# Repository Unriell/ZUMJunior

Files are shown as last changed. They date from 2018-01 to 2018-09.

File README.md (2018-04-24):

# ZUMJunior
BQ ZUM Junior integration on Arduino IDE

Please, visit the [project wiki](https://github.com/bq/ZUMJunior/wiki) for more information.

## Getting Started

### Prerequisites

You need to install latest [Arduino IDE](https://www.arduino.cc/en/Main/Software).

This package has been tested on Arduino IDE 1.8.5.

### Installing

To use the integration with Arduino IDE follow these steps:
1. Open Arduino IDE and go into File -> Preferences.
1. On "Additional Boards Manager URLs:" enter the link to [package_zumjunior_1_8_x_index.json](https://raw.githubusercontent.com/bq/ZUMJunior/master/package_zumjunior_1_8_x_index.json) [right click here and copy link] and press OK.
1. Go to Tools -> Boards -> Board Manager and you will find "ZUM Junior for Arduino 1.8.x" ready to be installed. Install latest version.

Now you can choose your Board **BQ ZUM Junior**.

You can also find some usefull examples for the board available on the IDE.

### Examples

The available examples are explained [here](https://github.com/bq/ZUMJunior/wiki/Examples).

## Flashing Bootloader

The bootloader can be flashed on ZUM Junior using another Arduino board as ISP or any other supported ISP programmer.
For further support check this [link](https://www.arduino.cc/en/Tutorial/ArduinoISP).

## License

This project is licensed under the GPL v3 license.

## Credits

This project relies on [Arduino IDE](https://github.com/arduino/Arduino) to work.

The project is based on [Elektor UNO R4](https://github.com/ElektorLabs/Arduino/)

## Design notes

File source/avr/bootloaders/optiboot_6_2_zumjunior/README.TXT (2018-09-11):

------------------------------------------------------------
bqZUM Junior

This is a slightly modified version to make optiboot compile for 
the ATmega16 too. 

The make rules for the Elektor boards are in Makefile.custom.
The easiest way to make this work is to copy this folder and its 
contents to:

  <Arduino>\hardware\arduino\avr\bootloaders\

where <Arduino> is the path to arduino.exe.

Open a command prompt and navigate to the newly added folder, ex:

  <Arduino>\hardware\arduino\avr\bootloaders\optiboot_6_2_zumjunior\

Enter this folder and then try make commands, like this:

  make atmega328pb LED=D2

This should result in a usable HEX file.
------------------------------------------------------------

This directory contains the Optiboot small bootloader for AVR
microcontrollers, somewhat modified specifically for the Arduino
environment.

Optiboot is more fully described here: http://github.com/Optiboot/optiboot
and is the work of Peter Knight (aka Cathedrow), building on work of Jason P
Kyle, Spiff, and Ladyada.  More recent maintenance and modifications are by
Bill Westfield (aka WestfW)

Arduino-specific issues are tracked as part of the Arduino project
at http://github.com/arduino/Arduino

Most of the information in this file is superceeded by the wiki content at
https://github.com/Optiboot/optiboot/wiki

It's till here "just in case."

------------------------------------------------------------

Building optiboot for Arduino.

Production builds of optiboot for Arduino are done on a Mac in "unix mode"
using CrossPack-AVR-20100115.  CrossPack tracks WINAVR (for windows), which
is just a package of avr-gcc and related utilities, so similar builds should
work on Windows or Linux systems.

One of the Arduino-specific changes is modifications to the makefile to
allow building optiboot using only the tools installed as part of the
Arduino environment, or the Arduino source development tree.  All three
build procedures should yield identical binaries (.hex files) (although
this may change if compiler versions drift apart between CrossPack and
the Arduino IDE.)

Building Optiboot in the Arduino IDE Install.

Work in the .../hardware/arduino/bootloaders/optiboot/ and use the
"omake <targets>" command, which just generates a command that uses
the arduino-included "make" utility with a command like:
    make OS=windows ENV=arduino <targets>
or  make OS=macosx ENV=arduino <targets>
On windows, this assumes you're using the windows command shell.  If
you're using a cygwin or mingw shell, or have one of those in your
path, the build will probably break due to slash vs backslash issues.
On a Mac, if you have the developer tools installed, you can use the
Apple-supplied version of make.
The makefile uses relative paths ("../../../tools/" and such) to find
the programs it needs, so you need to work in the existing optiboot
directory (or something created at the same "level") for it to work.

Building Optiboot in the Arduino Source Development Install.

In this case, there is no special shell script, and you're assumed to
have "make" installed somewhere in your path.
Build the Arduino source ("ant build") to unpack the tools into the
expected directory.
Work in Arduino/hardware/arduino/bootloaders/optiboot and use
    make OS=windows ENV=arduinodev <targets>
or  make OS=macosx ENV=arduinodev <targets>

Programming Chips Using the _isp Targets

The CPU targets have corresponding ISP targets that will actuall
program the bootloader into a chip. "atmega328_isp" for the atmega328,
for example.  These will set the fuses and lock bits as appropriate as
well as uploading the bootloader code.

ISP Targets in Version 5.0 and later:

The isp targets are now built using a separate "Makefile.isp" makefile,
which should make modification easier and more obvious.  This also fixes
the atmega8_isp target problem mentioned below.  The default
configuration assumes an ArduinoISP setup, but you will probably need to
update at least the serial port, since those are different for each
Arduino board and/or system/

ISP Targets in Version 4.6 and earlier:

The older makefiles default to using a USB programmer, but you can use a
serial programmer like ArduinoISP by changing the appropriate variables
when you invoke make:

   make ISPTOOL=stk500v1 ISPPORT=/dev/tty.usbserial-A20e1eAN  \
        ISPSPEED=-b19200 atmega328_isp

The "atmega8_isp" target does not currently work, because the mega8
doesn't have the "extended" fuse that the generic ISP target wants to
pass on to avrdude.  You'll need to run avrdude manually.

Standard Targets

I've reduced the pre-built and source-version-controlled targets
(.hex and .lst files included in the git repository) to just the
three basic 16MHz targets: atmega8, atmega16, atmega328.

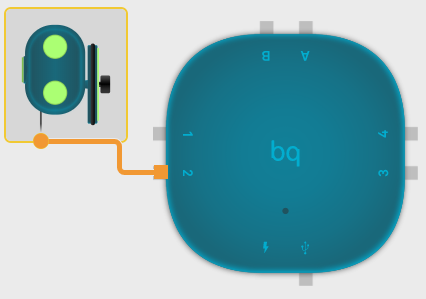
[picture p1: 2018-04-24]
images/examples/RotServo.PNG

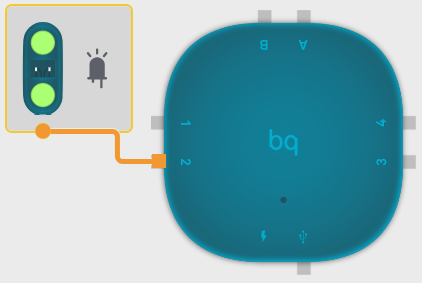
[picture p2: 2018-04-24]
images/examples/LED.PNG

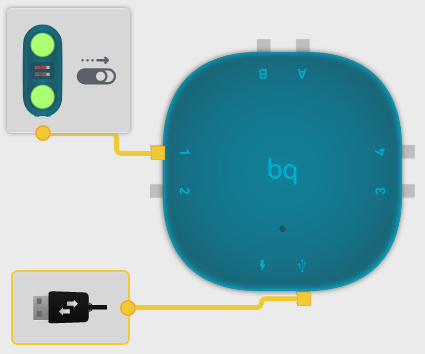
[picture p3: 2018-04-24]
images/examples/Slider.PNG

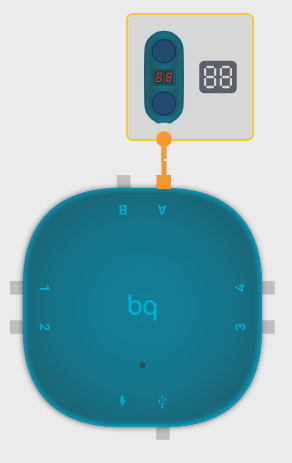
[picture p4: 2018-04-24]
images/examples/7SD.PNG

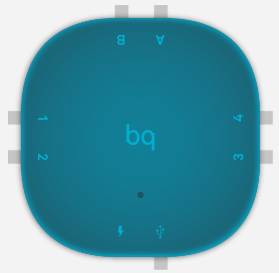
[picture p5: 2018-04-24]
images/examples/ZJ.PNG

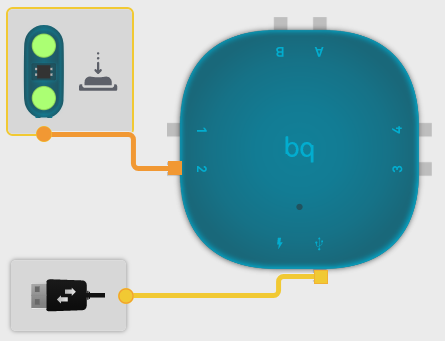
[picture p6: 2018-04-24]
images/examples/PushButton.PNG

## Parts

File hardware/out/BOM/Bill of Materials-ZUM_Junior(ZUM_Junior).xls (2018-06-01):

 |  |  | BILL OF MATERIALS
PROJECT: |  | ZUM_Junior.PrjPcb
TITLE: |  | Bill of Materials For Variant [ZUM_Junior] of Project [ZUM_Junior.PrjPcb] (No PCB Document Selected)
VARIANT: |  | ZUM_Junior
DOCUMENT: |  | Bill of Materials
AUTHOR : |  | Andrés Gullón
DATE : |  | 01/06/2018
REV: |  | <Parameter VersionControl_RevNumber not found>
NOTE | ITEM | Designator | Description | Quantity | Manufacturer | OrderingCode | Supplier | Manufacturer 2 | OrderingCode 2 | Manufacturer 3 | OrderingCode 3 | Manufacturer 4 | OrderingCode 4 | Manufacturer 5 | OrderingCode 5 | Footprint | Value
 | 1 | Buzzer 2 | Buzzer 8.5mm SMD | 1 | Qinlon | YX-8014S-05 |  |  |  |  |  |  |  |  |  | YX-8014S05-2.7 | Buzzer
 | 2 | C1, C2, C8, C11, C12, C14, C19, C20 | C0603_100nF_50V_±10%_X7R | 8 | Kemet | C0603C104K5RAC |  | AVX | 06035C104KAT2A |  |  |  |  |  |  | C0603 | 100nF ±10% 50V
 | 3 | C3, C4, C5, C10, C13, C18 | C0402_2.2uF_16V_±20%_X5R | 6 | TDK | C1005X5R1C225M050BC |  | Taiyo Yuden | EMK105ABJ225MV-F |  |  |  |  |  |  | C0402 | 2,2µF ±20% 16V
 | 4 | C6 |  | 1 | Kemet | C0603C105K3PAC |  |  |  |  |  |  |  |  |  | C0603 | 1uF ±10% 25V
 | 5 | C7, C24 |  | 2 | Murata | GRM31CR61E226KE15L |  |  |  |  |  |  |  |  |  | C1206 | 22uF ±10% 25V
 | 6 | C9, C21 |  | 2 | Kemet | T520B157M006ATE070 |  |  |  |  |  |  |  |  |  | CASE_B_3528-1411 | 150uF ±20% 6V3
 | 7 | C15, C16 | C0402_47pF_16V_±10% | 2 | Kemet | C0402C470K4GAC |  |  |  |  |  |  |  |  |  | C0402 | 47pF ±10% 16V
 | 8 | C17 | C0805_4700pF_250V_±10%_X7R | 1 | TDK | C2012X7R2E472K085AM |  |  |  |  |  |  |  |  |  | C0805 | 4,7nF ±10% 250V
 | 9 | C23 | C0805_1uF_50V_±10%_X7R | 1 | Kemet | C0805C105K5RAC |  |  |  |  |  |  |  |  |  | C0805 | 1uF ±10% 50V
 | 10 | C25 |  | 1 | Kemet | C0402C473K4RAC |  |  |  |  |  |  |  |  |  | C0402 | 47nF ±10% 16V
 | 11 | D1, D2 | Schottky Diode | 2 | NXP | BAT54S |  | Vishay | BAT54S |  |  |  |  |  |  | SOT23-3 | 200mA 30V
 | 12 | D3, D5 | Schottky Diode | 2 | NXP | PMEG3030EP |  |  |  |  |  |  |  |  |  | SOD128 | 3A 30V
 | 13 | D4b | RGB LED Reverse Mount | 1 | WÜrth Elektronik | 156125M173000 |  |  |  |  |  |  |  |  |  | LED1205 Reverse | RGB LED Rev.
 | 14 | F1 | Resettable Fuses | 1 | Bel Fuse | 0ZCG0260BF2B |  | Littelfuse | MINISMDC260F/16-2 | Bourns | MF-MSMF250/16X-2 |  |  |  |  | F1812
 | 15 | F2 | TVS Diode Array | 1 | Würth Elektronik | 82400152 |  | Bourns | CDSOT563-0502 |  |  |  |  |  |  | SOT563
 | 16 | F3 | Resettable Fuses | 1 | Bourns | MF-MSMF050-2 |  |  |  |  |  |  |  |  |  | F1812
 | 17 | J1, J2, J3, J4, J5, J6 | RJ11 4p4c SMD | 6 | Kycon | GMX-SMT2-N-44-TR |  | Cenvalsa | 7641 – T441 |  |  | Molex | 95501-6449 |  |  | RJ11 SMD
 | 18 | L1 | Semi-shielded power inductor | 1 | Bourns | SRN8040-2R2Y |  |  |  |  |  |  |  |  |  | SRN8040 | 2,2µH 6,3A
 | 19 | L2 | L0603_120R_0,025R_3000mA | 1 | Murata | BLM18SG121TN1D |  |  |  |  |  |  |  |  |  | L0603 | 120R 0,025R 3000mA
 | 20 | L3 |  | 1 | Würth Elektronik | 742792012 |  |  |  |  |  |  |  |  |  | L0805 | 33R 0,008R 4000mA
 | 21 | POWER | DC Power Jack 6.4mm 2.0mm | 1 | Würth Elektronik | 694106106102 |  |  |  |  |  |  |  |  |  | 694106106102 | DC Jack
 | 22 | Q1 | N-MOSFET transistor | 1 | Diodes | DMG301NU-13 |  |  |  |  |  |  |  |  |  | SOT23-3
 | 23 | Q2, Q3 | P-MOSFET transistor | 2 | Diodes Incorporated | DMP2035U-7 |  |  |  |  |  |  |  |  |  | SOT23-3
 | 24 | R1, R8 | R0603_1M_0.1W_±5% | 2 | Vishay | CRCW06031M00JN |  |  |  |  |  |  |  |  |  | R0603 | 1M ±5% 0.1W
 | 25 | R2 | R0402_10R_0.063W_±1% | 1 | Vishay | CRCW040210R0FK |  | Yageo | RC0402FR-0710RL |  |  |  |  |  |  | R0402 | '=Resistance+' '+Tolerance+' '+Power
 | 26 | R3, R17 | R0402_1k_0.063W_±5% | 2 | Vishay | CRCW04021K00JN |  |  |  |  |  |  |  |  |  | R0402 | 1k ±5% 0.063W
 | 27 | R4, R11, R19, R20, R21 | R0402_330R_0.063W_±5% | 5 | Vishay | CRCW0402330RJN |  |  |  |  |  |  |  |  |  | R0402 | 330R ±5% 0.063W
 | 28 | R7, R12, R14, R23 | R0402_100k_0.063W_±1%, [NoValue] | 4 | Vishay | CRCW0402100KFK |  |  |  |  |  |  |  |  |  | R0402 | 100k ±1% 0.063W
 | 29 | R10, R16, R22, R25 |  | 4 | Vishay | CRCW040210K0FK |  |  |  |  |  |  |  |  |  | R0402 | 10k ±1% 0.063W
 | 30 | R13 |  | 1 | Vishay | CRCW040252K3FK |  |  |  |  |  |  |  |  |  | R0402 | 52,3k ±1% 0.063W
 | 31 | R15 | R0402_82k_0.063W_±1% | 1 | Vishay | CRCW040282K0FK |  | Yageo | RC0402FR-0782KL |  |  |  |  |  |  | R0402 | 82k ±1% 0.063W
 | 32 | R18 | R0402_75k_0.063W_±1% | 1 | Vishay | CRCW040275K0FK |  | Yageo | RC0402FR-0775KL |  |  |  |  |  |  | R0402 | 75k ±1% 0.063W
 | 33 | R24 | R0402_30k_0.063W_±1% | 1 | Vishay | CRCW040230K0FK |  |  |  |  |  |  |  |  |  | R0402 | 30k ±1% 0.063W
 | 34 | U1 | 8-bit Microcontrollers - MCU 32KB In-system Flash 20MHz 1.8V-5.5V | 1 | Atmel | ATMEGA328PB-AU |  |  |  |  |  |  |  |  |  | TQFP32
 | 35 | U2 | DCDC Step Down Vout= 1-5V; Vin= 12-17V | 1 | MPS | MP1477GTF-Z |  |  |  |  |  |  |  |  |  | SOT-563 - MP1477H
 | 36 | U3 | USB to UART Bridge | 1 | Silicon Labs | CP2104-F03-GMR |  |  |  |  |  |  |  |  |  | QFN24_no_power
 | 37 | U4 | LDO Vin: 3-40V Vout: 1.2-15V @300mA | 1 | Monolithic Power Systems | MP2019GN-Z |  |  |  |  |  |  |  |  |  | SOIC8 EP
 | 38 | USB | Micro USB Type B W/ Rear Pegs | 1 | FCI | 10118194-0001LF |  |  |  |  |  |  |  |  |  | USB_B_W_REAR_PEGS
 | 39 | Y1 | Resonator 16MHz | 1 | Murata | CSTCE16M0V53-R0 |  |  |  |  |  |  |  |  |  | Resonator_1.3x3.2 | 16MHz
NOTES:

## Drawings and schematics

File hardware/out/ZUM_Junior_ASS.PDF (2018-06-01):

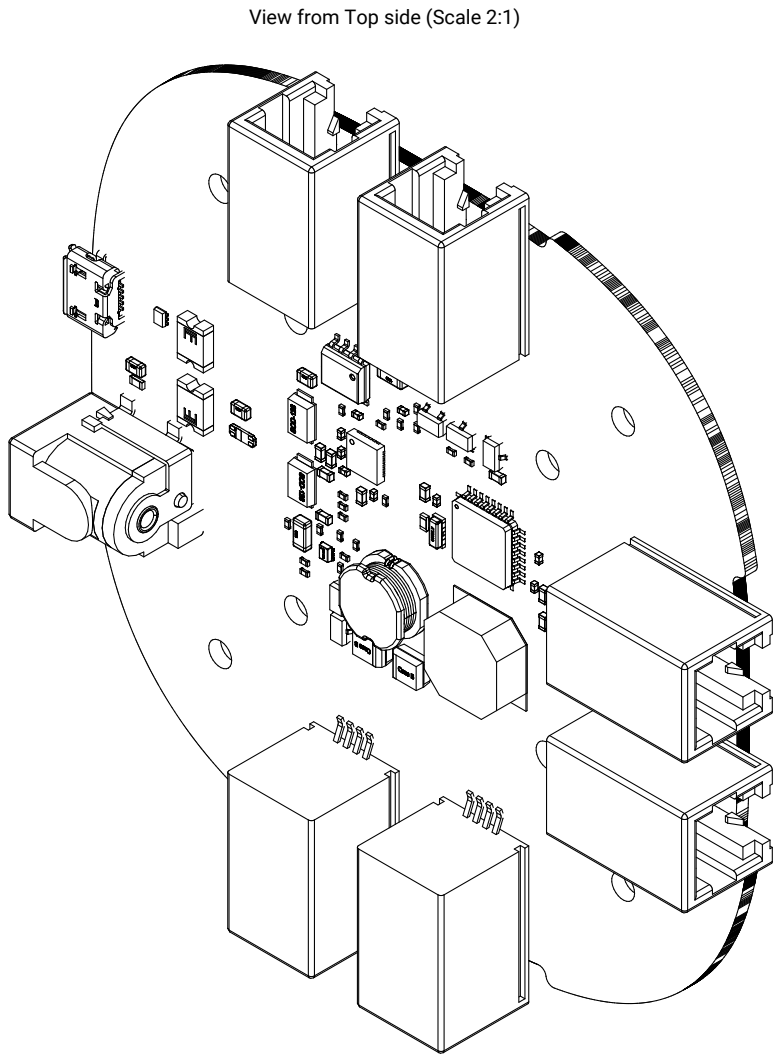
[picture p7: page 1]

View from Top side (Scale 2:1)

ZUM_Junior | SCALE | 2:1

REVISION | =1.G.3
UNIT | UNLESS OTHERWISE SPECIFIED: DIMENSIONS ARE IN MILLIMETERS

PROJECTION

A3 | SHEET 1 OF 2

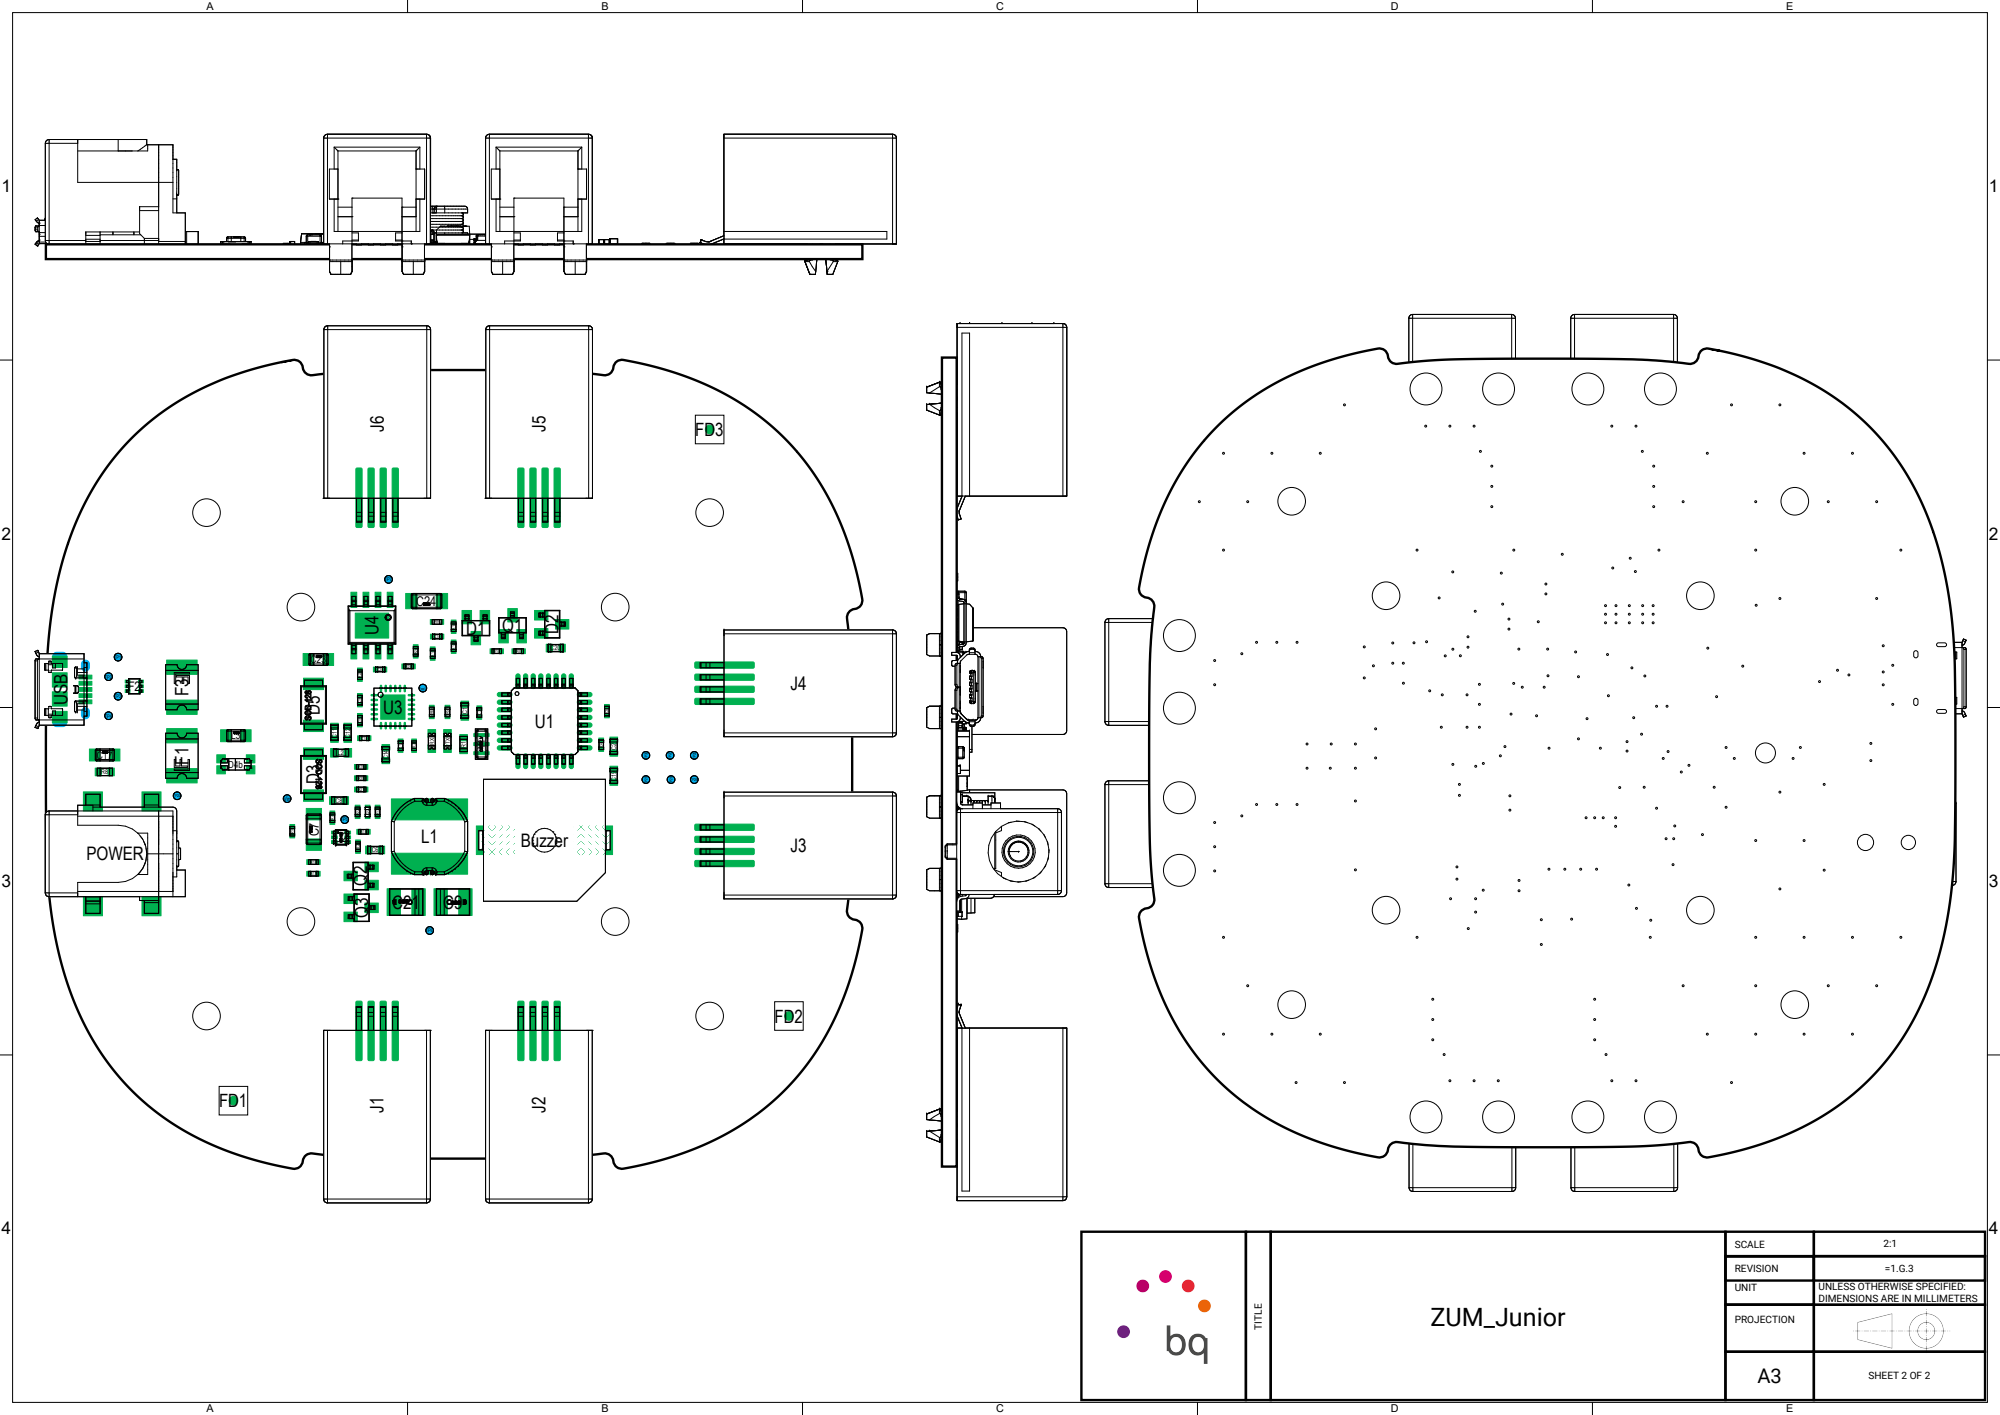
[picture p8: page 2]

ZUM_Junior | SCALE | 2:1

REVISION | =1.G.3
UNIT | UNLESS OTHERWISE SPECIFIED: DIMENSIONS ARE IN MILLIMETERS

PROJECTION

A3 | SHEET 2 OF 2

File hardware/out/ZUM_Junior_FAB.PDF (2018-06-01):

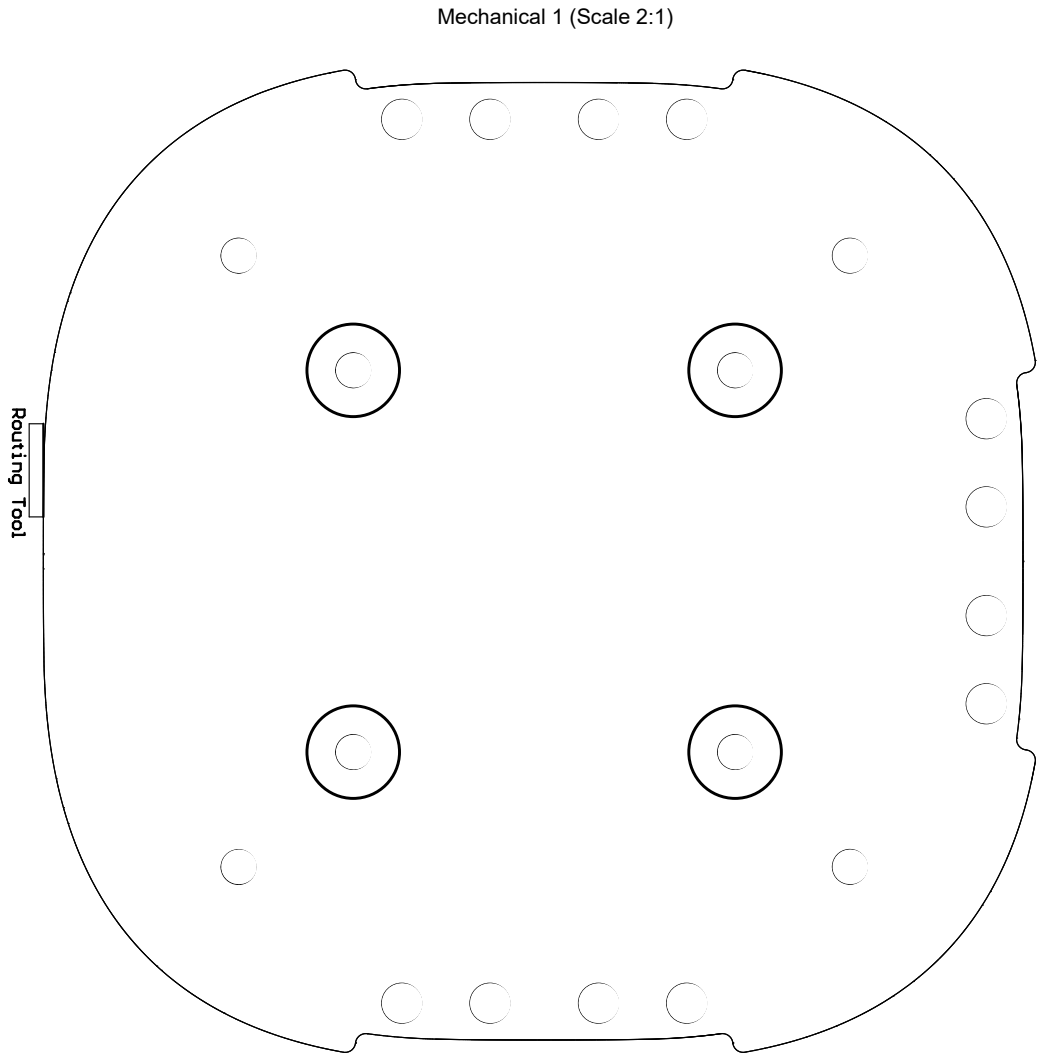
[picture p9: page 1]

SURFACE FINISH: | | SOLDERMASK COLOR: TITLE ZUM_Junior | SCALE | 2:1

Immersion Tin | Blue | SILKSCREEN COLOR: White

REVISION | =1.G.3
UNIT | UNLESS OTHERWISE SPECIFIED: DIMENSIONS ARE IN MILLIMETERS

PROJECTION

A3 | SHEET 1 OF 3

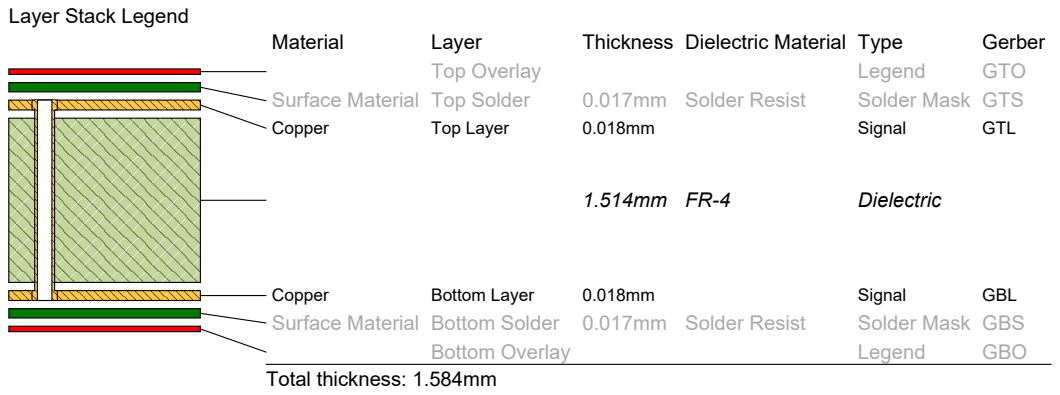
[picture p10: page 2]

SURFACE FINISH: | | SOLDERMASK COLOR: TITLE | SCALE | 2:1

Immersion Tin | Blue | SILKSCREEN COLOR: White

REVISION | =1.G.3
UNIT | UNLESS OTHERWISE SPECIFIED:

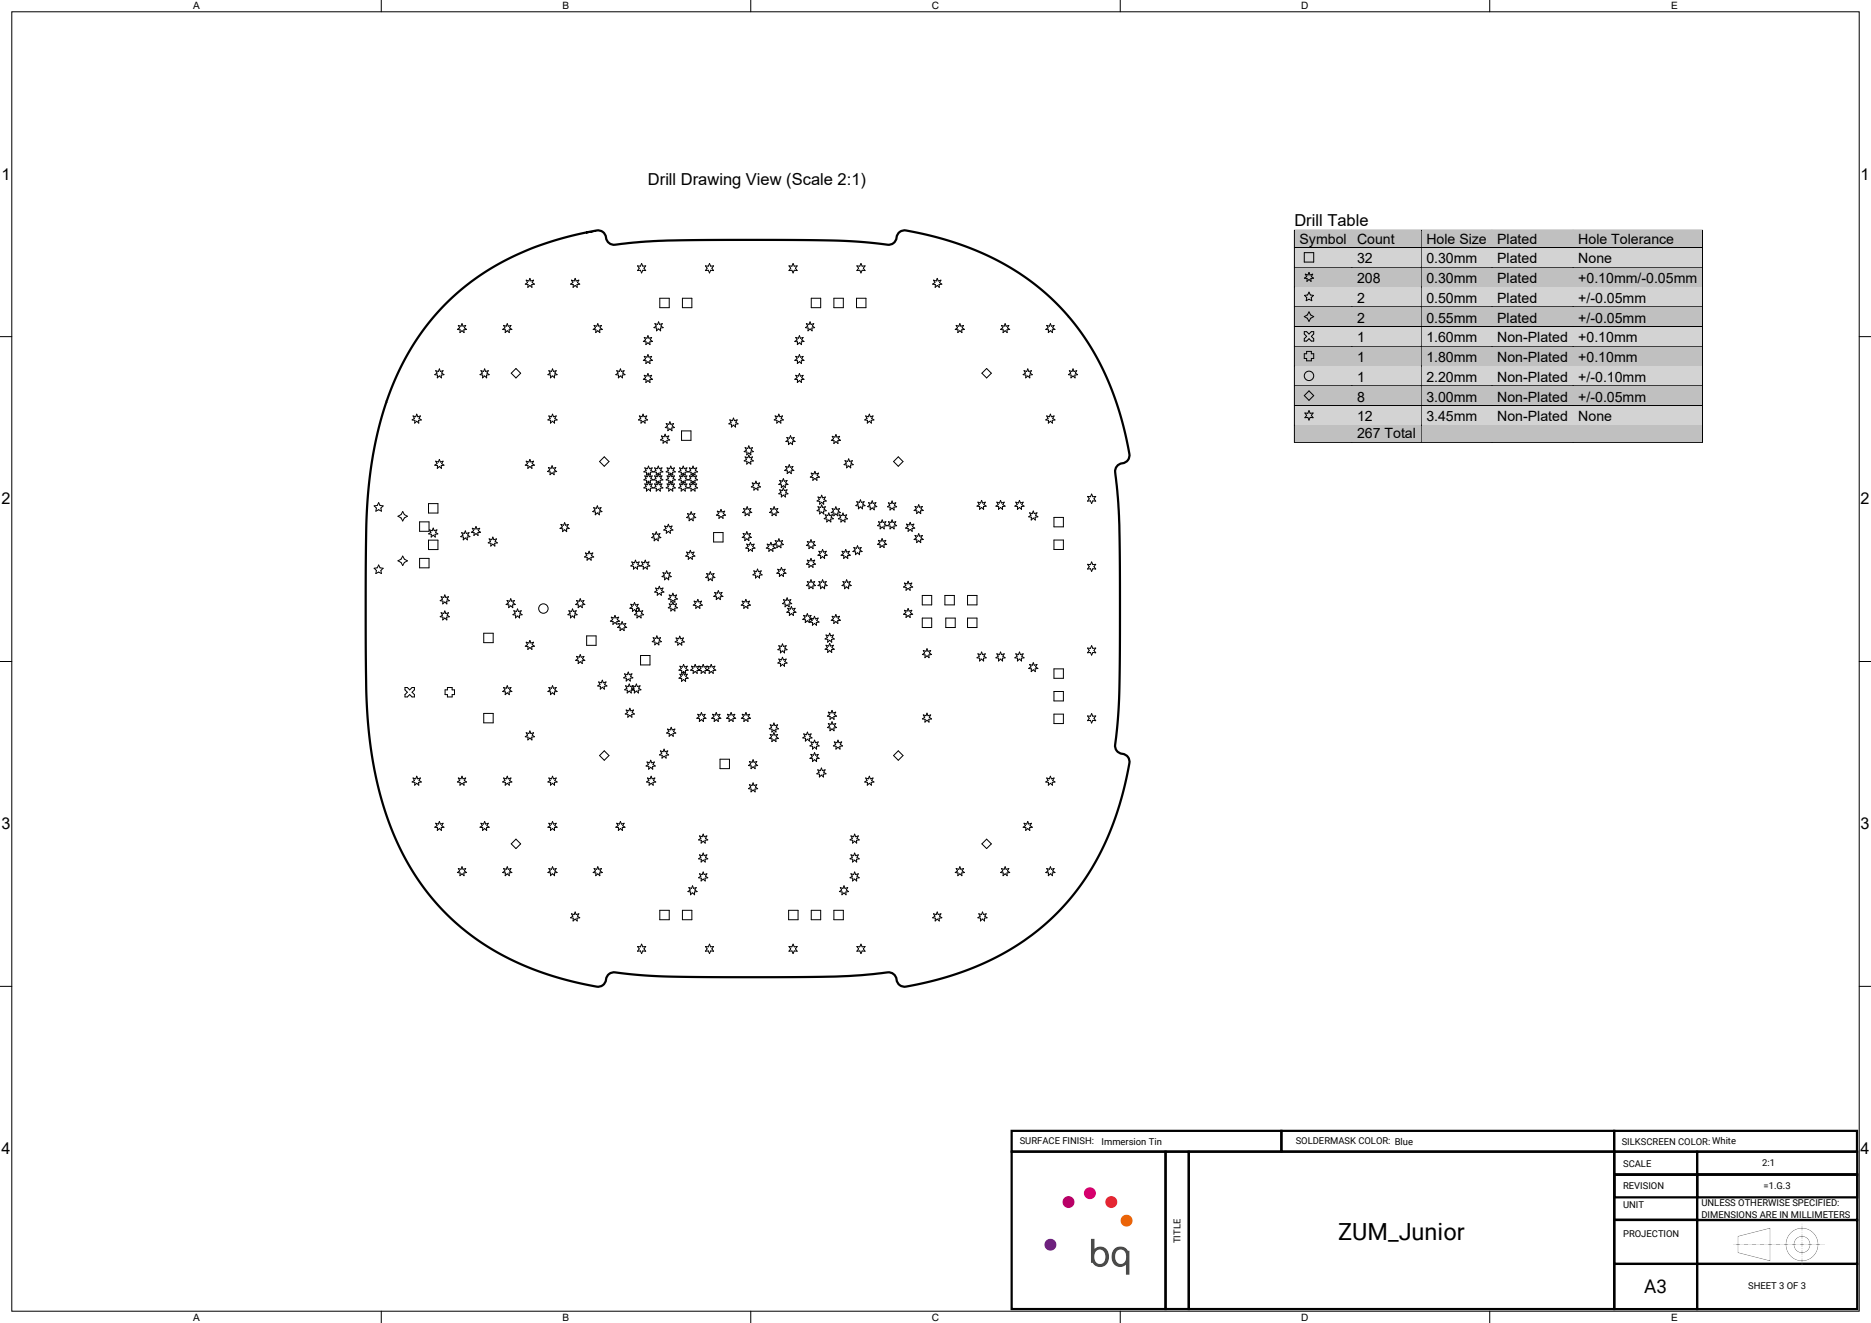
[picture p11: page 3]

Drill Drawing View (Scale 2:1)

Symbol | Count | Hole Size | Plated | Hole Tolerance

32 | 0.30mm | Plated | None
208 | 0.30mm | Plated | +0.10mm/-0.05mm
2 | 0.50mm | Plated | +/-0.05mm
2 | 0.55mm | Plated | +/-0.05mm
1 | 1.60mm | Non-Plated | +0.10mm
1 | 1.80mm | Non-Plated | +0.10mm
1 | 2.20mm | Non-Plated | +/-0.10mm
8 | 3.00mm | Non-Plated | +/-0.05mm
12 | 3.45mm | Non-Plated | None
267 Total

SURFACE FINISH: | | SOLDERMASK COLOR: TITLE | SCALE | 2:1

Immersion Tin | Blue | SILKSCREEN COLOR: White

REVISION | =1.G.3
UNIT | UNLESS OTHERWISE SPECIFIED:

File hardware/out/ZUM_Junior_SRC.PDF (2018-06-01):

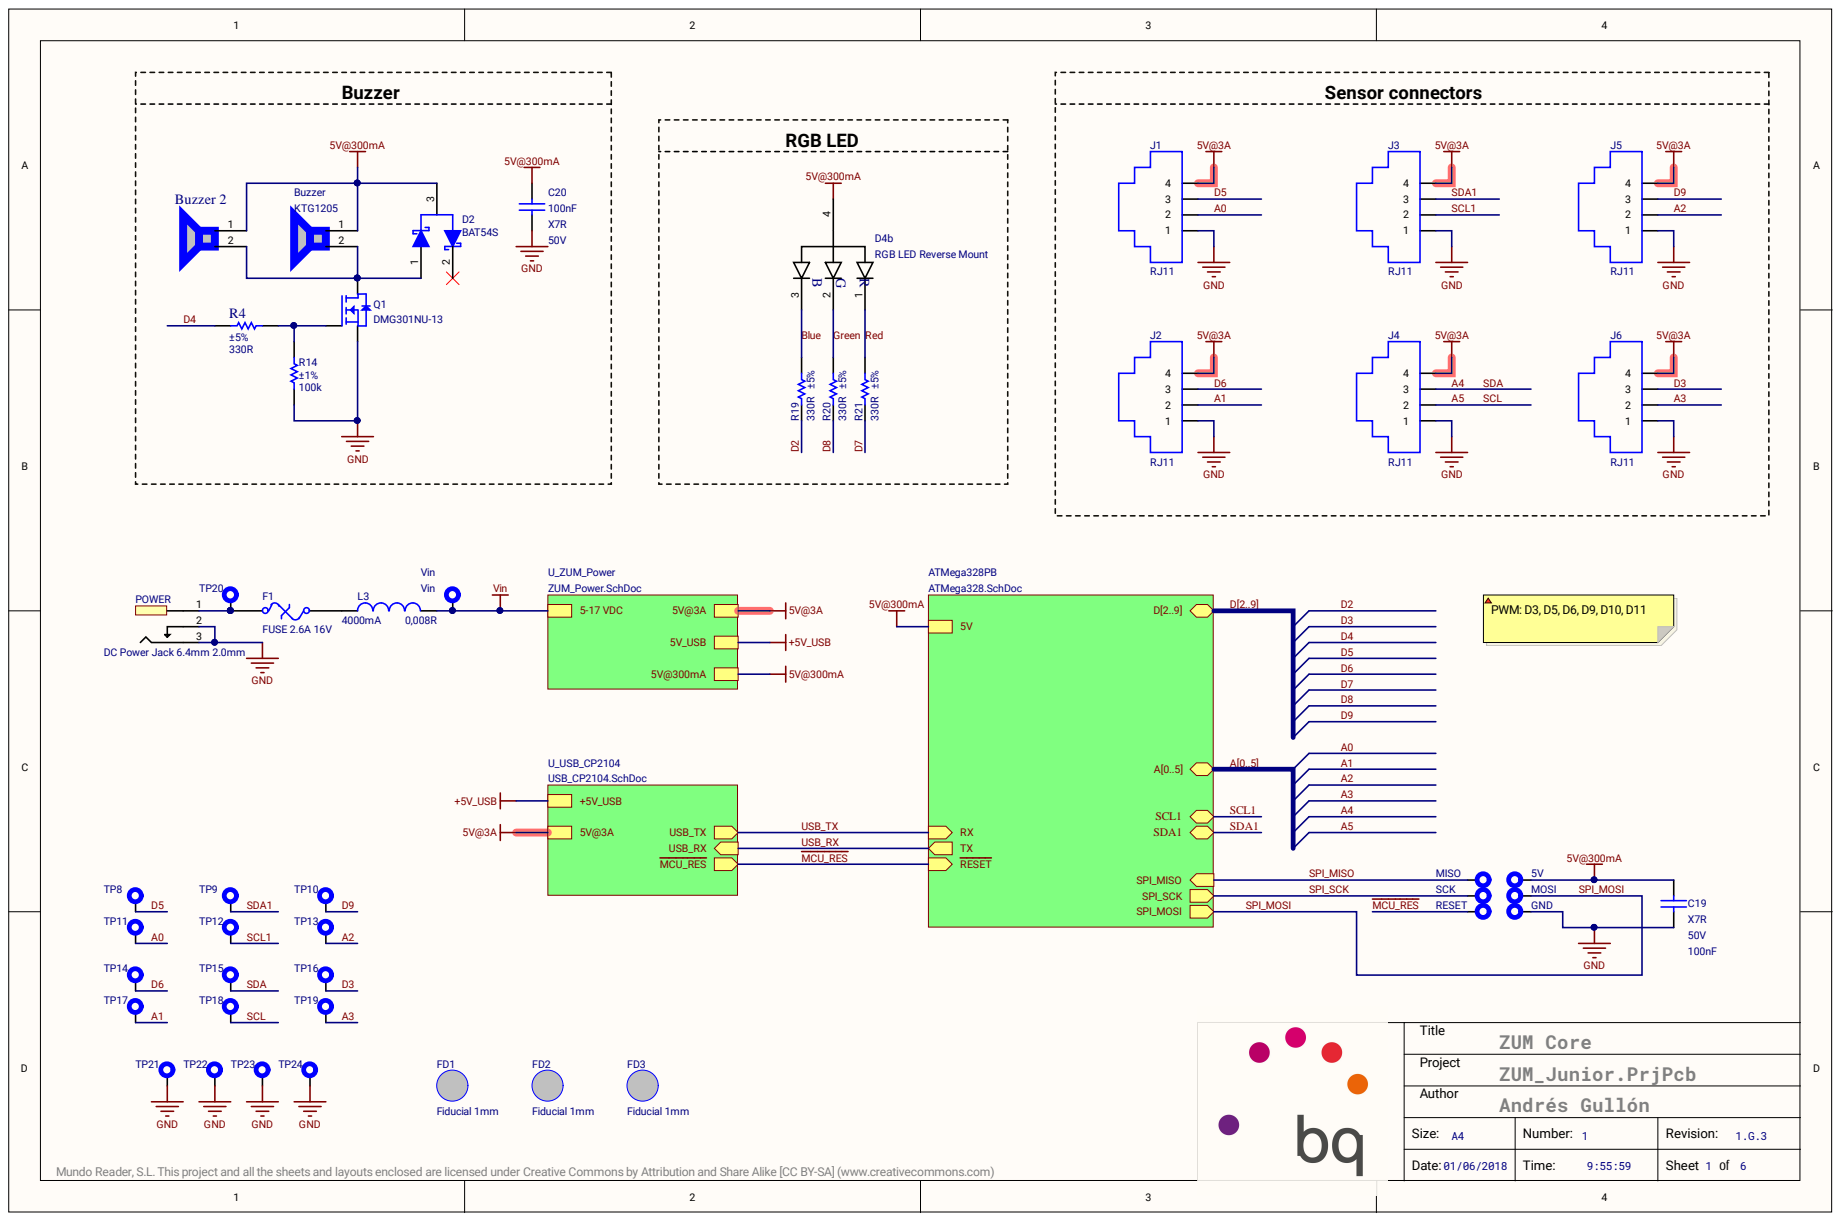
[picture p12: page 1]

Siz e : A 4 | Numbe r : | R evision: 1 . G . 3

D ate / | Time : : | She e t of

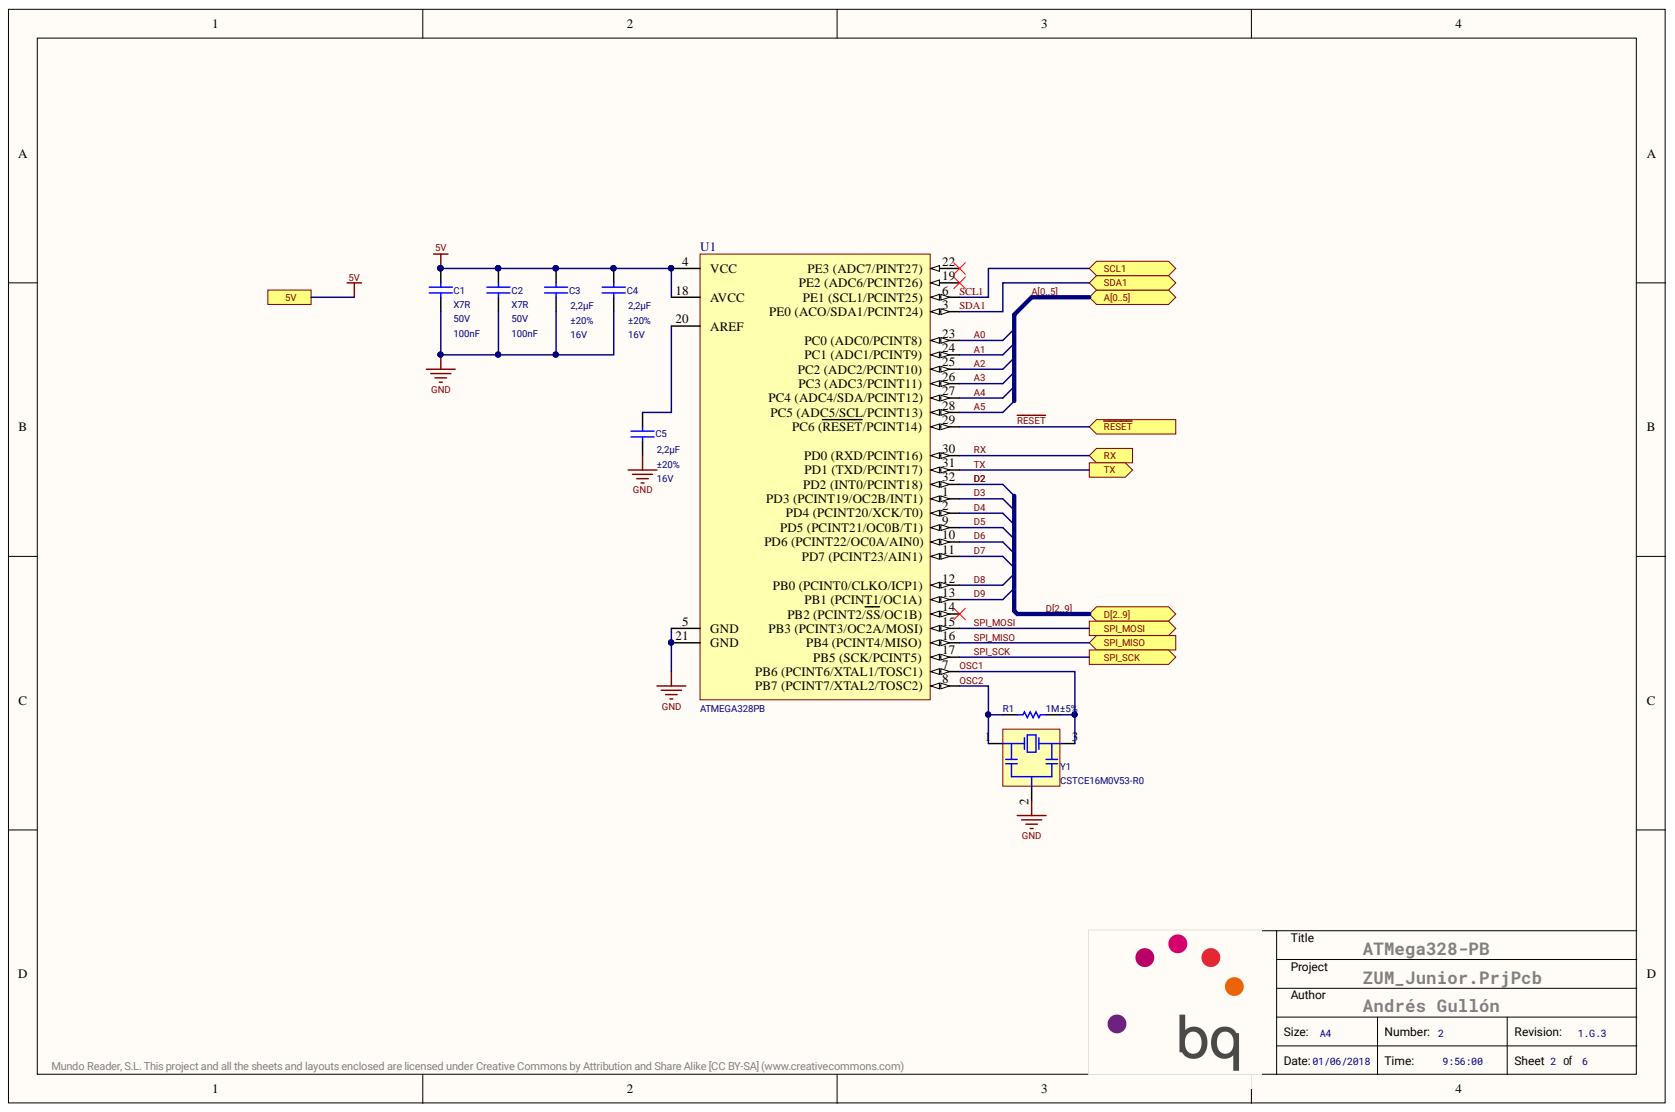
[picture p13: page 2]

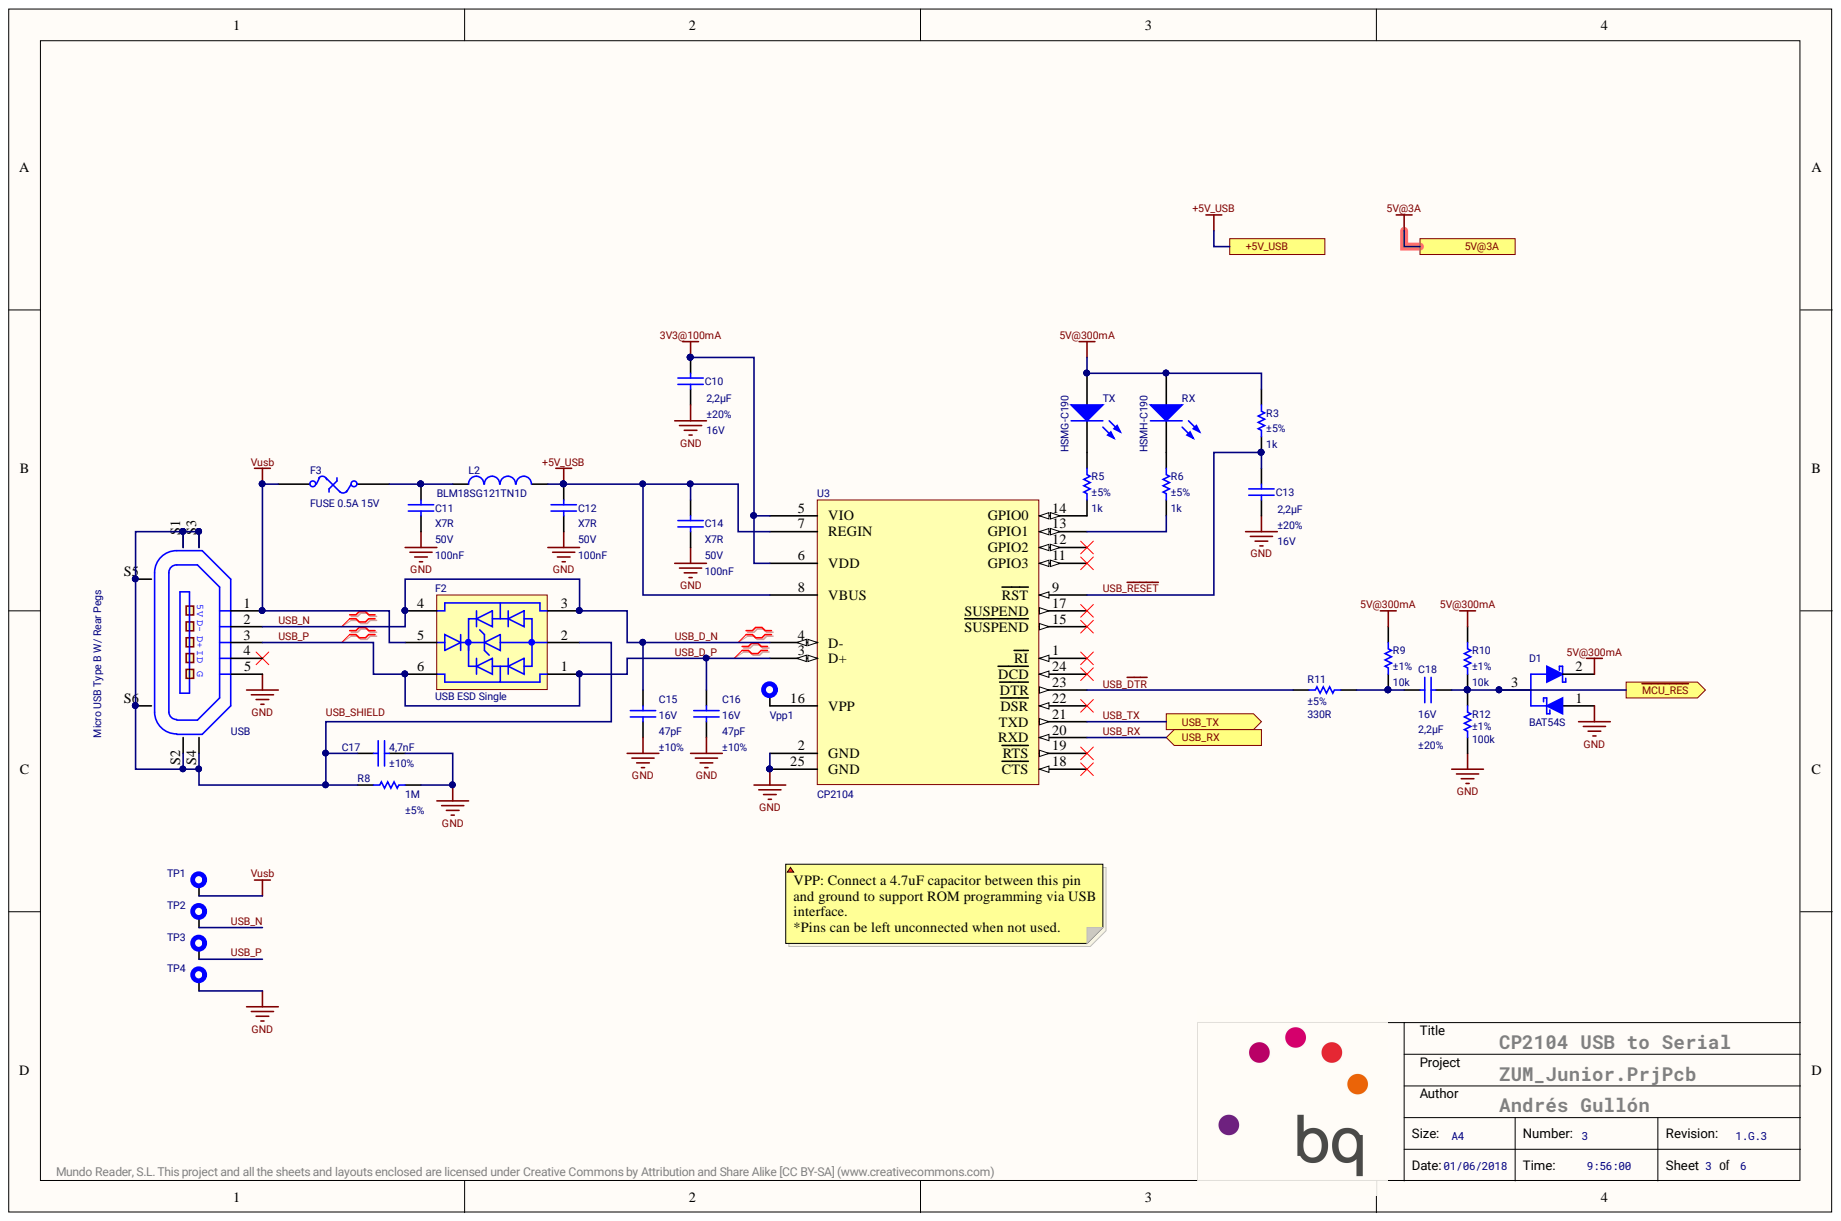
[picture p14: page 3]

USB icro USB Type B W/ Rear Pegs

and ground to support ROM programming via USB
interface.
*Pins can be left unconnected when not used.

Size: A4 | Number: 3 | Revision: 1.G.3

Date: 01/06/2018 | Time: 9:56:00 | Sheet 3 of 6

Mundo Reader, S.L. This project and all the sheets and layouts enclosed are licensed under Creative Commons by Attribution and Share Alike [CC BY-SA](www.creativecommons.com)

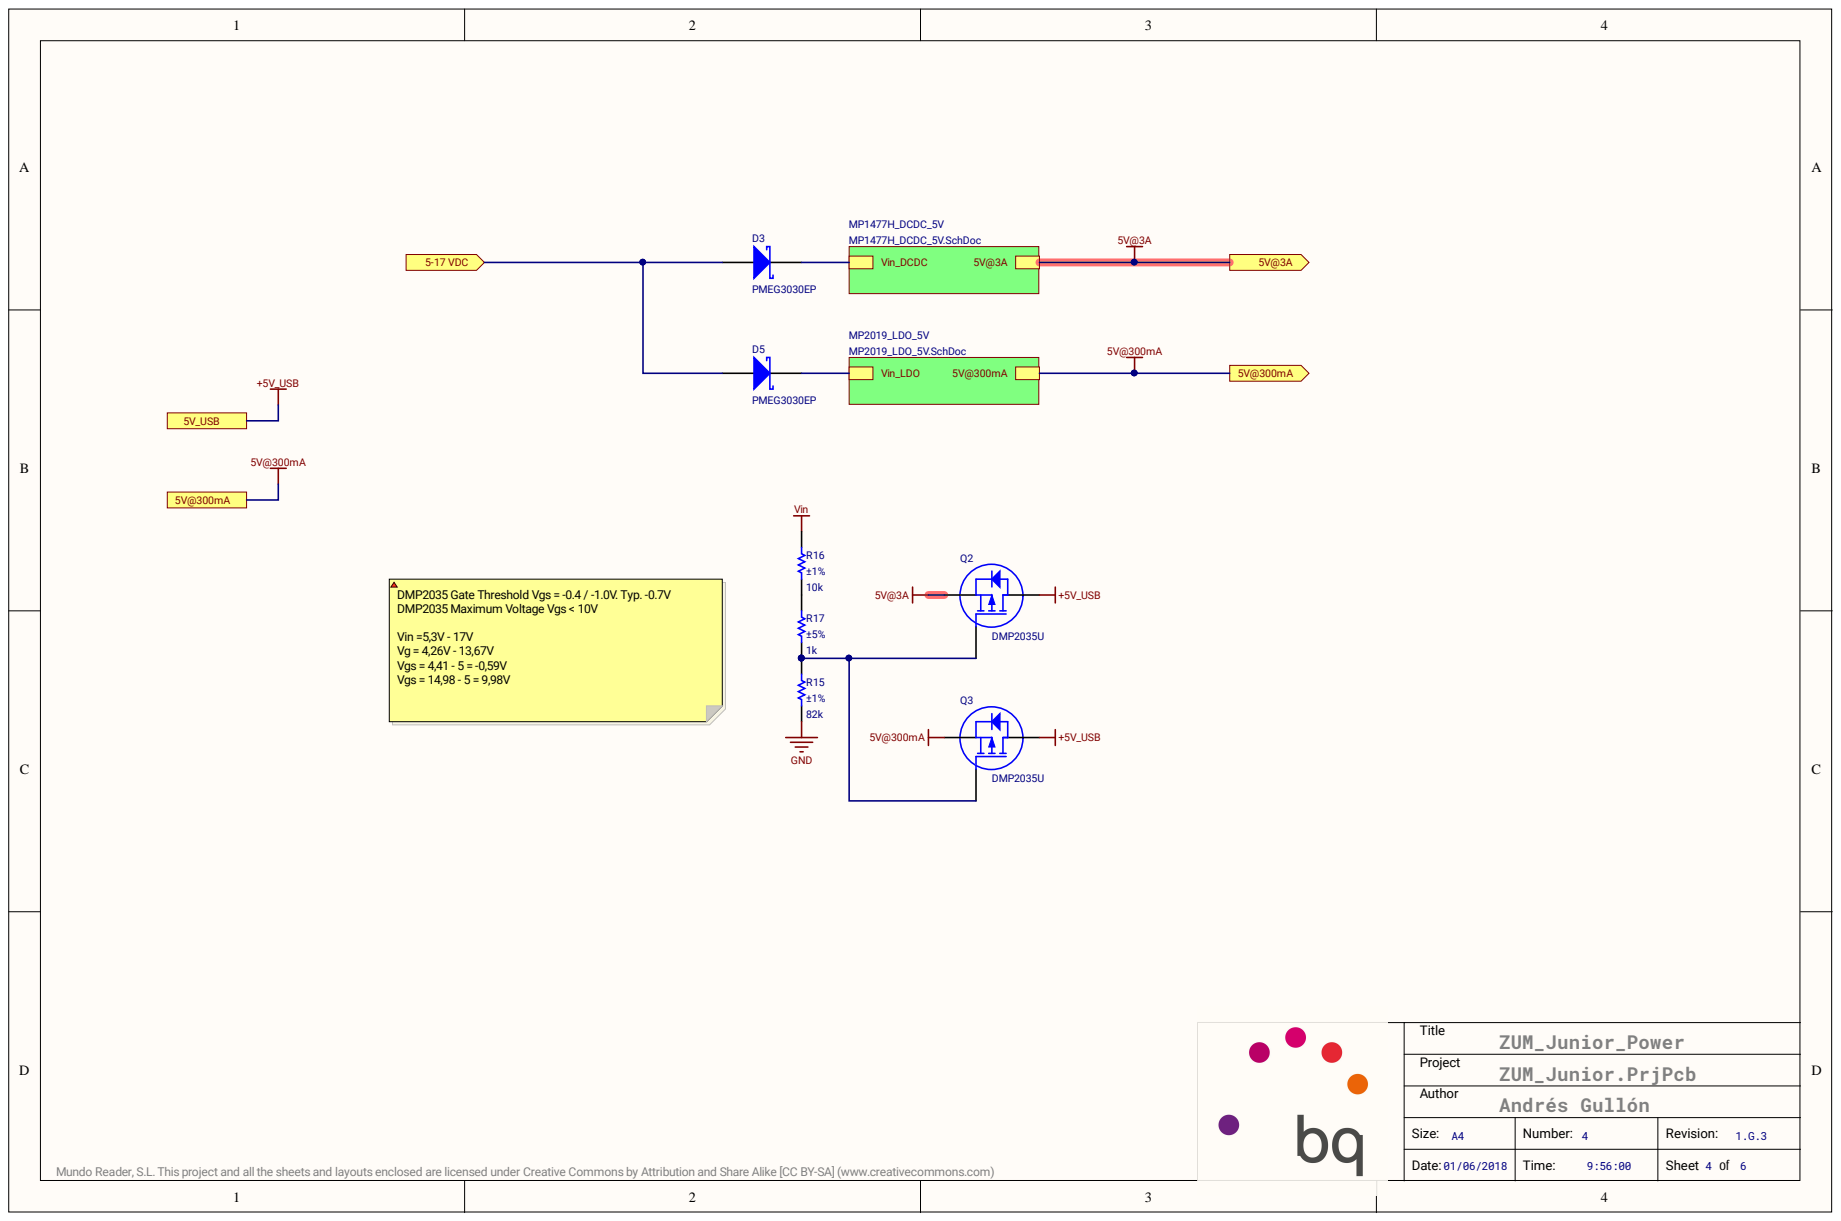
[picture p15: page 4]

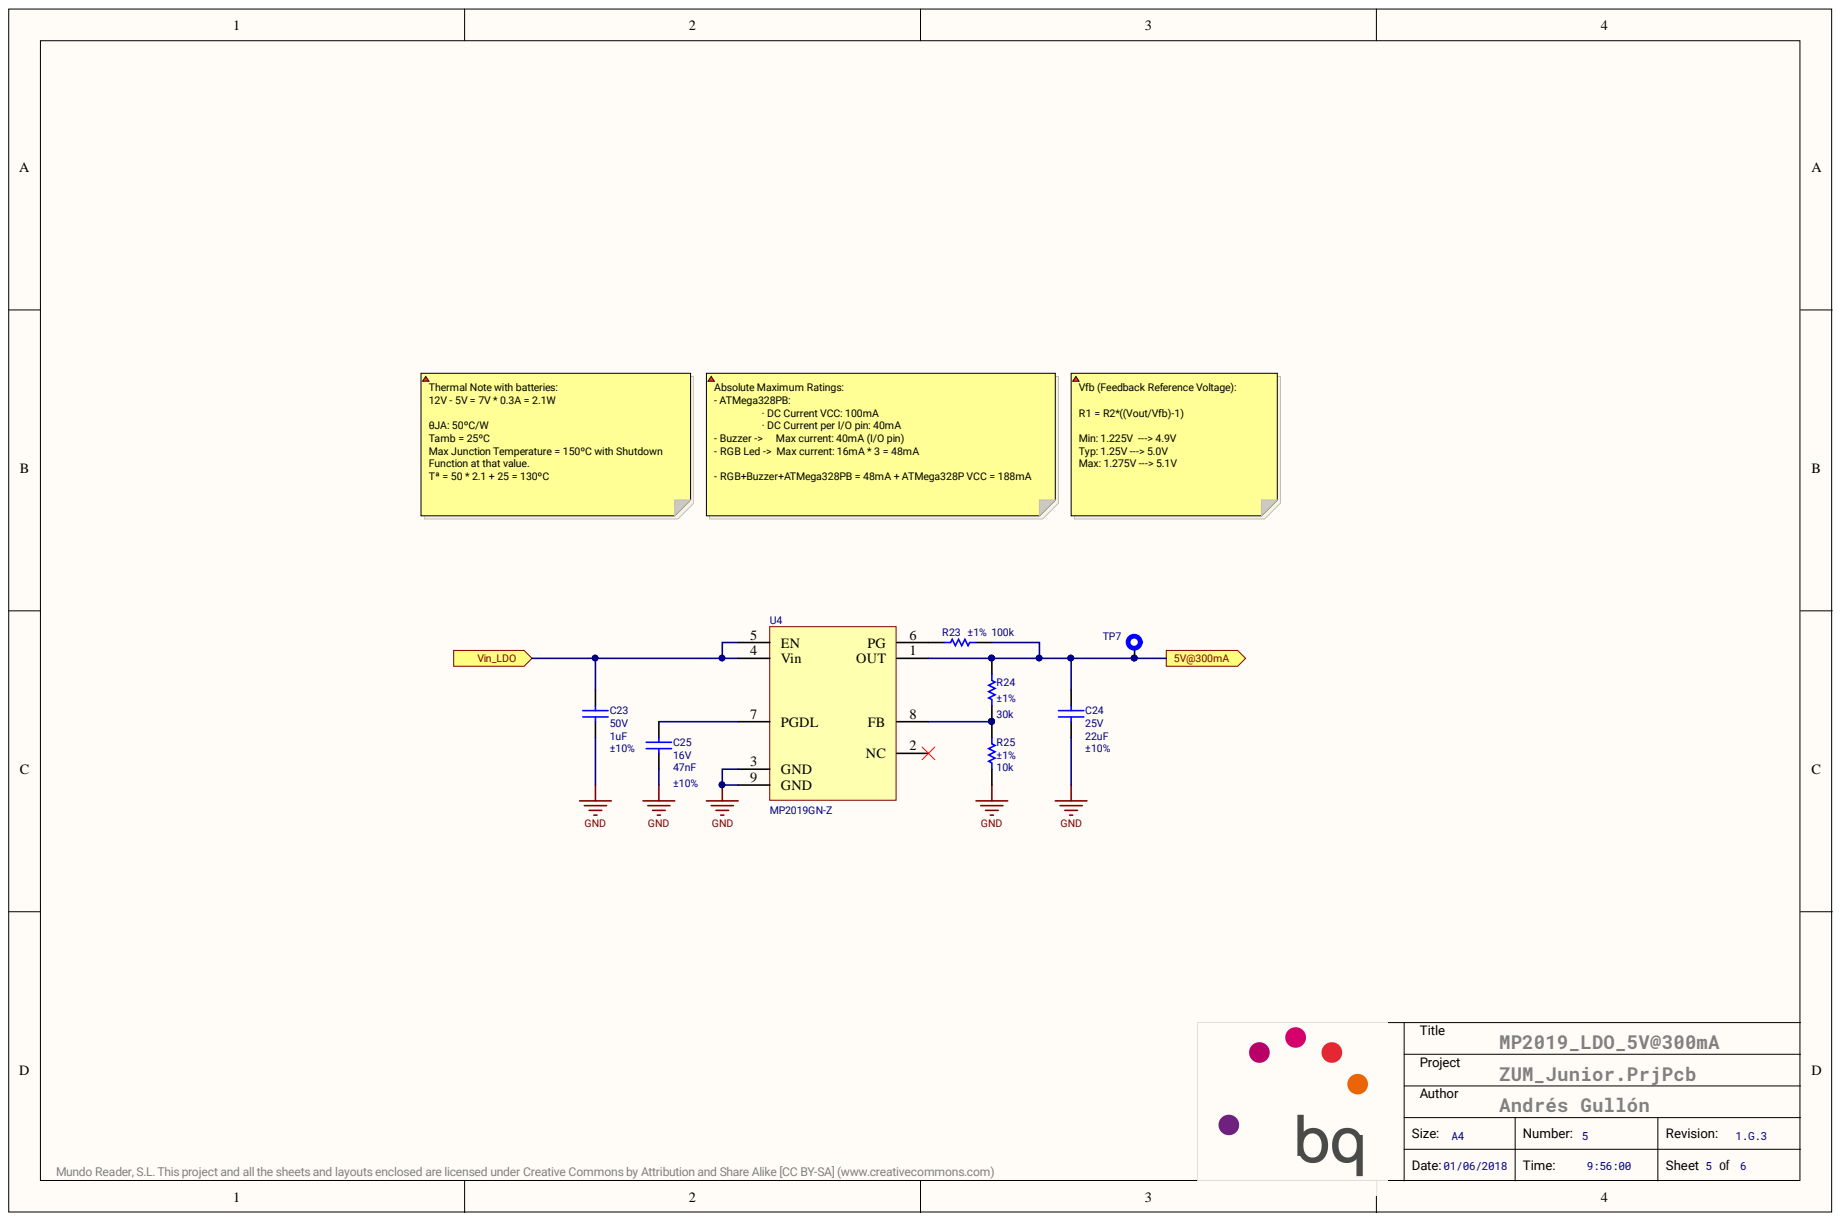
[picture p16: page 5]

on at that value

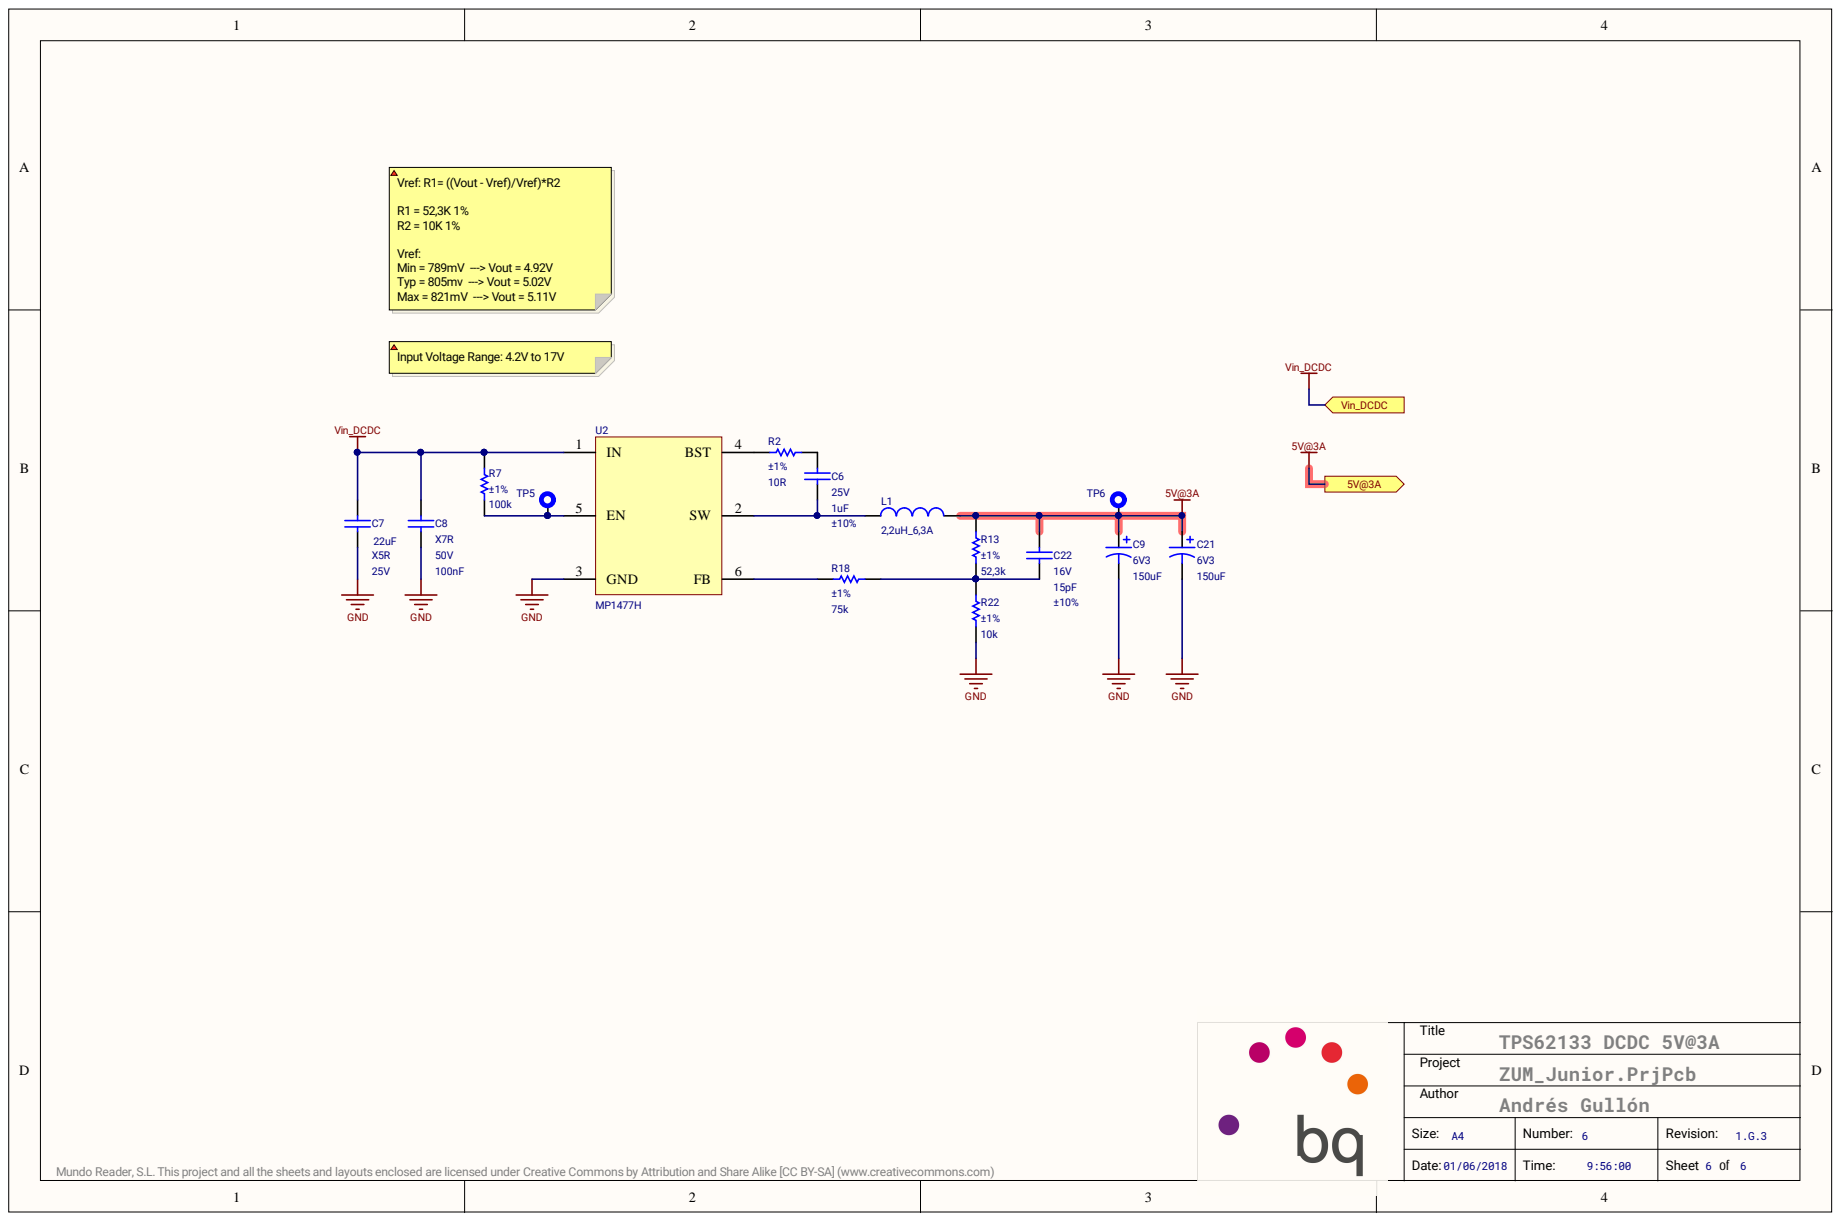
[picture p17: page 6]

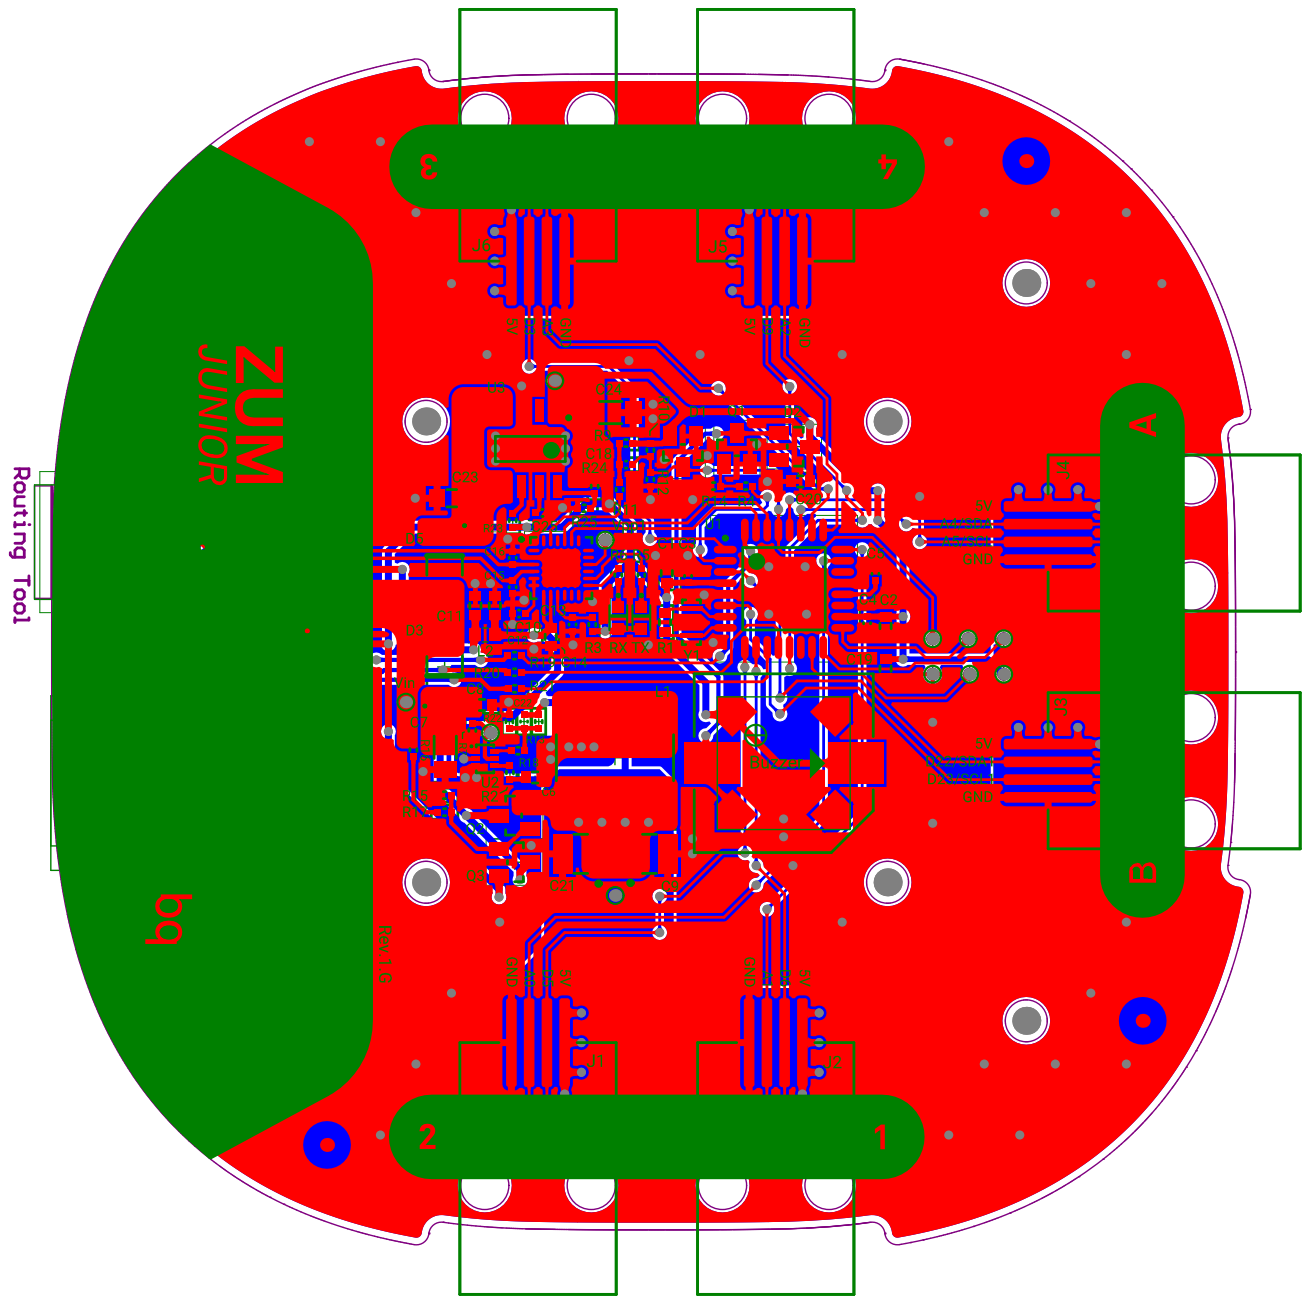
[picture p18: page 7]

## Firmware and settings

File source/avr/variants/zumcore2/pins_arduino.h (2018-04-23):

/*
  pins_arduino.h - Pin definition functions for Arduino
  Part of Arduino - http://www.arduino.cc/

  Copyright (c) 2007 David A. Mellis

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
  $Id: wiring.h 249 2007-02-03 16:52:51Z mellis $
*/

#ifndef Pins_Arduino_h
#define Pins_Arduino_h

#include <avr/pgmspace.h>

#include "avr/iom328p.h"

#undef LED_BUILTIN
#define LED_BUILTIN  (8)

// Pin  0 -  7: PD0-7
// Pin  8 - 13: PB0-5
// Pin 14 - 19: PC0-5
// Pin 20 - 21: PE2-3
// Pin 22 - 23: PE0-1

#define NUM_DIGITAL_PINS  (24) // ZUM Junior and ZUM Core 2 have 24 instead of 20 GPIOs.
#define NUM_ANALOG_INPUTS   (8) // ZUM Junior and ZUM Core 2 have 8 instead of 6 analog inputs.

#define analogInputToDigitalPin(p)  (((p)<8)? (p)+14 : -1)

#define digitalPinHasPWM(p)  ((p)<=3) || (p)==5 || (p)==6 || (p)==9 || (p)==10 || (p)==11)

// SPI, SPI is also SPI0
static const uint8_t SS   = 10; // PB2
static const uint8_t MOSI = 11; // PB3
static const uint8_t MISO = 12; // PB4
static const uint8_t SCK  = 13; // PB5
// SPI0
static const uint8_t SS0   = 10; // PB2
static const uint8_t MOSI0 = 11; // PB3
static const uint8_t MISO0 = 12; // PB4
static const uint8_t SCK0  = 13; // PB5
// SPI1
static const uint8_t SS1   = 20; // PE2
static const uint8_t MOSI1 = 21; // PE3
static const uint8_t MISO1 = 14; // PC0
static const uint8_t SCK1  = 15; // PC1

// I2C / TWI, SDA/SCL is also SDA0/SCL0
static const uint8_t SDA = 18; // PC4
static const uint8_t SCL = 19; // PC5
// I2C0
static const uint8_t SDA0 = 18; // PC4
static const uint8_t SCL0 = 19; // PC5
// I2C1
static const uint8_t SDA1 = 22; // PE0
static const uint8_t SCL1 = 23; // PE1

// Analog inputs
static const uint8_t A0 = 14; // PC0
static const uint8_t A1 = 15; // PC1
static const uint8_t A2 = 16; // PC2
static const uint8_t A3 = 17; // PC3
static const uint8_t A4 = 18; // PC4
static const uint8_t A5 = 19; // PC5
static const uint8_t A6 = 20; // PE2
static const uint8_t A7 = 21; // PE3

// Pin Change Interrupt
#define digitalPinToPCICR(p)    (((p)<=23) ? (&PCICR) : ((uint8_t *)0))
                                // Port D         Port B          Port C     Port C
#define digitalPinToPCICRbit(p) (((p)<=7)? 2 : (((p)<=13)? 0 : (((p)<=19)? 1 : 3)))
#define digitalPinToPCMSK(p)    (((p)<=7)? (&PCMSK2) : (((p)<=13)? (&PCMSK0) : (((p)<=19)? (&PCMSK1) : (((p)<=23)? (&PCMSK3) : ((uint8_t *)0)))))
#define digitalPinToPCMSKbit(p) (((p)<=7)? (p) : (((p)<=13)? ((p)-8) : (((p)<=19)? ((p)-14) : ((p)<=21)? ((p)-17) : ((p)-22))))

#define digitalPinToInterrupt(p)  ((p) == 2 ? 0 : ((p) == 3 ? 1 : NOT_AN_INTERRUPT))

#ifdef ARDUINO_MAIN


// these arrays map port names (e.g. port B) to the
// appropriate addresses for various functions (e.g. reading
// and writing)
const uint16_t PROGMEM port_to_mode_PGM[] = {
	NOT_A_PORT,
	NOT_A_PORT,
	(uint16_t) &DDRB,
	(uint16_t) &DDRC,
	(uint16_t) &DDRD,
	(uint16_t) &DDRE,
};

const uint16_t PROGMEM port_to_output_PGM[] = {
	NOT_A_PORT,
	NOT_A_PORT,
	(uint16_t) &PORTB,
	(uint16_t) &PORTC,
	(uint16_t) &PORTD,
	(uint16_t) &PORTE,
};

const uint16_t PROGMEM port_to_input_PGM[] = {
	NOT_A_PORT,
	NOT_A_PORT,
	(uint16_t) &PINB,
	(uint16_t) &PINC,
	(uint16_t) &PIND,
	(uint16_t) &PINE,
};

const uint8_t PROGMEM digital_pin_to_port_PGM[] = {
	PD, /* 0 */
	PD,
	PD,
	PD,
	PD,
	PD,
	PD,
	PD,
	PB, /* 8 */
	PB,
	PB,
	PB,
	PB,
	PB,
	PC, /* 14 */
	PC,
	PC,
	PC,
	PC,
	PC,
	PE, /* 20 */
	PE,
	PE,
	PE,
};

const uint8_t PROGMEM digital_pin_to_bit_mask_PGM[] = {
	_BV(0), /* 0, port D */
	_BV(1),
	_BV(2),
	_BV(3),
	_BV(4),
	_BV(5),
	_BV(6),
	_BV(7),
	_BV(0), /* 8, port B */
	_BV(1),
	_BV(2),
	_BV(3),
	_BV(4),
	_BV(5),
	_BV(0), /* 14, port C */
	_BV(1),
	_BV(2),
	_BV(3),
	_BV(4),
	_BV(5),
	_BV(2), /* 20, port E, PE2 is AD6 */
	_BV(3), // PE3 is AD7
	_BV(0), // PE0
	_BV(1), // PE1
};

const uint8_t PROGMEM digital_pin_to_timer_PGM[] = {
	TIMER3A, /* 0 - port D */
	TIMER4A,
	TIMER3B,
	TIMER2B,
	NOT_ON_TIMER,
	TIMER0B,
	TIMER0A,
	NOT_ON_TIMER,
	NOT_ON_TIMER, /* 8 - port B */
	TIMER1A,
	TIMER1B,
	TIMER2A,
	NOT_ON_TIMER,
	NOT_ON_TIMER,
	NOT_ON_TIMER, /* 14 - port C */
	NOT_ON_TIMER,
	NOT_ON_TIMER,
	NOT_ON_TIMER,
	NOT_ON_TIMER,
	NOT_ON_TIMER,
	NOT_ON_TIMER, /* 20 - port E */
	NOT_ON_TIMER,
	NOT_ON_TIMER,
	NOT_ON_TIMER,
};

#endif
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

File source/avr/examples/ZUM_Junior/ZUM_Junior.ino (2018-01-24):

/*************************************************************/
/**                 BQ ZUM JUNIOR - Example                 **/
/**                                                         **/
/** Connections:                                            **/
/**   - Port 1 (D9/A2): LED Yellow                          **/
/**   - Port 2 (D3/A3):                                     **/
/**   - Port 3 (D5/A0): LED Green                           **/
/**   - Port 4 (D6/A1): LED Red                             **/
/**   - Port A (D20/D21/I2C1): 7 Segment Display            **/
/**   - Port B (A4/A5/I2C0): Sensor Multiple                **/
/*************************************************************/
/**  Temperature Displayed in 7 Segment Display             **/
/**  Distance represented in RGB LED                        **/
/**  In low light condition White LEDs are turned ON        **/
/**  Color sensor is represented in RGB LED                 **/
/*************************************************************/
/**  Needed external library: SoftPWM                       **/
/*************************************************************/

#include <BQZUM_DistSensor.h>
#include <BQZUM_TempSensor.h>
#include <BQZUM_ColorSensor.h>
#include <BQZUM_SegmentDisplay.h>
#include <SoftPWM.h>

#define   LED_RGB_RED   7
#define   LED_RGB_GREEN 8
#define   LED_RGB_BLUE  2
#define   BUZZER        4

#define   BLOQ_LED_G_GREEN  A0
#define   BLOQ_LED_G_WHITE  5
#define   BLOQ_LED_Y_YELLOW A2
#define   BLOQ_LED_Y_WHITE  9
#define   BLOQ_LED_R_RED    A1
#define   BLOQ_LED_R_WHITE  6

#define   NOTE_E6       1319
#define   NOTE_B4       494
#define   QUARTER_NOTE  250
#define   EIGHT_NOTE    125

// Declare all sensors
BQZUM_DistSensor      ALPSSensor;
BQZUM_ColorSensor     ColorSensor;
BQZUM_TempSensor      TempSensor;
BQZUM_SegmentDisplay  SegmentDisplay;

void setup() {
  ALPSStat    ALPS_Status = ALPS_OK;
  TempStat    Temp_Status = TEMP_OK;
  ColorStat   Color_Status = COLOR_OK;
  SegmentStat Segment_Status = SEGMENT_OK;
  
  pinMode (LED_RGB_RED,   OUTPUT);
  pinMode (LED_RGB_GREEN, OUTPUT);
  pinMode (LED_RGB_BLUE,  OUTPUT);
  pinMode (BUZZER,        OUTPUT);
  pinMode (BLOQ_LED_G_GREEN, OUTPUT);
  pinMode (BLOQ_LED_G_WHITE, OUTPUT);
  pinMode (BLOQ_LED_R_RED,   OUTPUT);
  pinMode (BLOQ_LED_R_WHITE, OUTPUT);
 
  digitalWrite(LED_RGB_RED,   HIGH);
  digitalWrite(LED_RGB_GREEN, HIGH);
  digitalWrite(LED_RGB_BLUE,  HIGH);
  digitalWrite(BLOQ_LED_G_GREEN, LOW);
  digitalWrite(BLOQ_LED_G_WHITE, LOW);
  digitalWrite(BLOQ_LED_R_RED,   LOW);
  digitalWrite(BLOQ_LED_R_WHITE, LOW);

  Serial.begin(115200);
  Serial.println("-------------------------------------------");
  Serial.println("-    BQ ZUM JUNIOR - SENSORS AND LEDS     -");
  Serial.println("-------------------------------------------");
  Serial.println();

  SoftPWMBegin(SOFTPWM_INVERTED);

  // Can't use tone and SoftPWM at the same time
  //tone(BUZZER, NOTE_E6, QUARTER_NOTE);
  //tone(BUZZER, NOTE_B4, EIGHT_NOTE);
    
  ALPS_Status = ALPSSensor.begin(0);
  if (ALPS_Status == ALPS_OK)
  {
    Serial.println(" - ALPS Sensor running.");
  }
  delay(100);
    
  Color_Status = ColorSensor.begin(0);
  if (Color_Status == COLOR_OK)
  {
    Serial.println(" - Color Sensor running.");
  }
  delay(100);
  
  Temp_Status = TempSensor.begin(0);
  if (Temp_Status == TEMP_OK)
  {
    Serial.println(" - Temperature Sensor running.");
  }
  delay(100);

  Segment_Status = SegmentDisplay.begin(1);
  if (Segment_Status == TEMP_OK)
  {
    Serial.println(" - 7 Segment Display Sensor running.");
  }
  delay(100);

  SegmentDisplay.displayChar('b','q');

  delay(2000);
}

void loop() {
  // put your main code here, to run repeatedly:
  float     f_Red         = 0;
  float     f_RedAvr      = 0;
  float     f_Green       = 0;
  float     f_GreenAvr    = 0;
  float     f_Blue        = 0;
  float     f_BlueAvr     = 0;
  int       i_Red         = 0;
  int       i_Green       = 0;
  int       i_Blue        = 0;
  float     f_Clear       = 0;
  float     f_Temperature = 0;
  uint16_t  ui16_Distance = 0;
  float     f_AmbientLight = 0;
  char      c_Temperature[2];
  
  f_Temperature = TempSensor.getTemp();
  ColorSensor.getColor(&f_Red, &f_Green, &f_Blue, &f_Clear);
  ui16_Distance = ALPSSensor.getDistance();
  f_AmbientLight = ALPSSensor.getAL();

  Serial.print("Temp (ºC): ");
  Serial.print(f_Temperature);
  Serial.print("\tAL (lux): ");
  Serial.print(f_AmbientLight);
  Serial.print("\tDistance: ");
  Serial.println(ui16_Distance);
  Serial.print("COLOR Red:");
  Serial.print(f_Red);
  Serial.print("\tGreen:");
  Serial.print(f_Green);
  Serial.print("\tBlue:");
  Serial.print(f_Blue);
  Serial.print("\tClear:");
  Serial.print(f_Clear);
  Serial.println();
  Serial.println();

  // Distance
  if (ui16_Distance > 1500) {
    digitalWrite(BLOQ_LED_R_RED, LOW);
    digitalWrite(BLOQ_LED_G_GREEN, HIGH);
  }
  else if (ui16_Distance > 400) {
    digitalWrite(BLOQ_LED_R_RED, LOW);
    digitalWrite(BLOQ_LED_G_GREEN, LOW);
  }
  else {
    digitalWrite(BLOQ_LED_R_RED, HIGH);
    digitalWrite(BLOQ_LED_G_GREEN, LOW);
  }

  // Ambient Light
  if (f_AmbientLight < 100) {
    digitalWrite(BLOQ_LED_G_WHITE, HIGH);
    digitalWrite(BLOQ_LED_Y_WHITE, HIGH);
    digitalWrite(BLOQ_LED_R_WHITE, HIGH);
  }
  else {
    digitalWrite(BLOQ_LED_G_WHITE, LOW);
    digitalWrite(BLOQ_LED_Y_WHITE, LOW);
    digitalWrite(BLOQ_LED_R_WHITE, LOW);
  }

  // Color
  f_RedAvr    = 100*f_Red / (f_Red + f_Green + f_Blue);
  f_GreenAvr  = 100*f_Green / (f_Red + f_Green + f_Blue);
  f_BlueAvr   = 100*f_Blue / (f_Red + f_Green + f_Blue);
  i_Red = f_RedAvr;
  i_Green = f_GreenAvr;
  i_Blue = f_BlueAvr;
  SoftPWMSetPercent(LED_RGB_RED, i_Red);
  SoftPWMSetPercent(LED_RGB_GREEN, i_Green);
  SoftPWMSetPercent(LED_RGB_BLUE, i_Blue);

  // Temperature
  dtostrf(f_Temperature,2,0,c_Temperature);
  SegmentDisplay.displayChar(c_Temperature[0],c_Temperature[1]);
  
  delay(500);
}

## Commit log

2018-01-24 Added information on how to use the json file on Arduino IDE.
2018-02-10 ZUM Junior LED example
2018-02-10 ZUM Junior Button Example
2018-02-10 ZUM Junior Rotation Servo Example
2018-02-10 ZUM Junior Servo Example
2018-02-17 ports updated to enclosure
2018-02-18 updated pin data types in examples
2018-03-11 Examples added. Color Sensor, Buzzer and RGBLED
2018-04-03 added function to read color sensor components
2018-04-10 Changed print to println for easy reading.
2018-04-11 Changed readme to access directly json on latest version so there is no need to change the link on Arduino configuration.
2018-04-24 Add multi sensor image for examples.
2018-06-01 Add hardware folder.
    [ATMega328.SchDoc, Bill of Materials-ZUM_Junior(ZUM_Junior).xls, MP1477H_DCDC_5V.SchDoc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]
2018-09-11 Update README.TXT
    Modified to explain only ZUM Junior boards.

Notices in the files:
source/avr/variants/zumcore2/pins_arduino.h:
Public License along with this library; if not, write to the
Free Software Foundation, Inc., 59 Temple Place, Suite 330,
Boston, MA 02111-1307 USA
